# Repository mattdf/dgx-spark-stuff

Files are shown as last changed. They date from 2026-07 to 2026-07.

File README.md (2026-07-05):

# DGX Spark Stuff

This repo will collect various DGX Spark-related work over time. 

## OpenSCAD Rack for 4x Sparks

[CAD](CAD): OpenSCAD-based stackable DGX Spark rack, along with exported STL parts and a reference render. The CAD folder includes the main source model, printable tray/top/joiner exports (4-spark rack configuration), and a DGX Spark reference body used for fit and preview.

I suggest printing this in PC (or PETG if you really can't print PC), because the surface temperatures of the sparks can get up to 60c under high load long term, and PLA has a glass transition temperature of ~55c so it will soften too much under load. The bottom tray can be PLA, but using PC for the rest is best.

<table align="center">
	<tr>
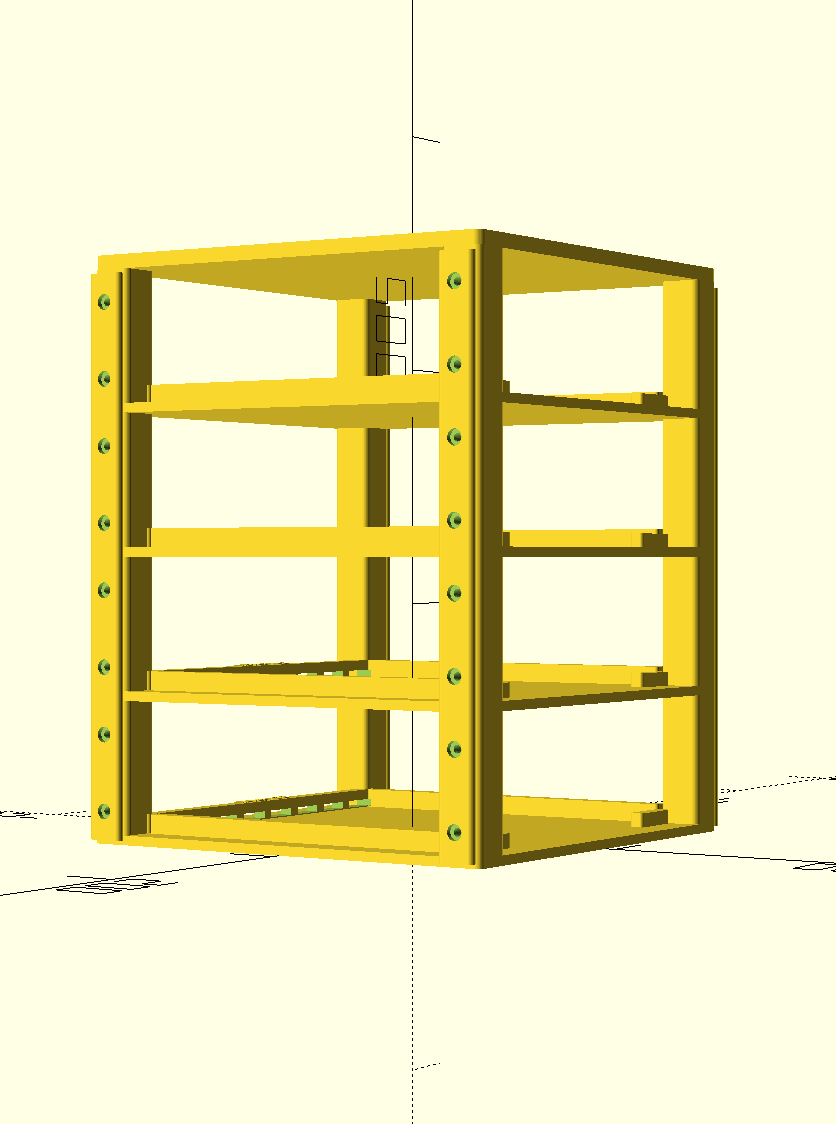
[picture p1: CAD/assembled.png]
Rendered assembly
		<td align="center"></td>
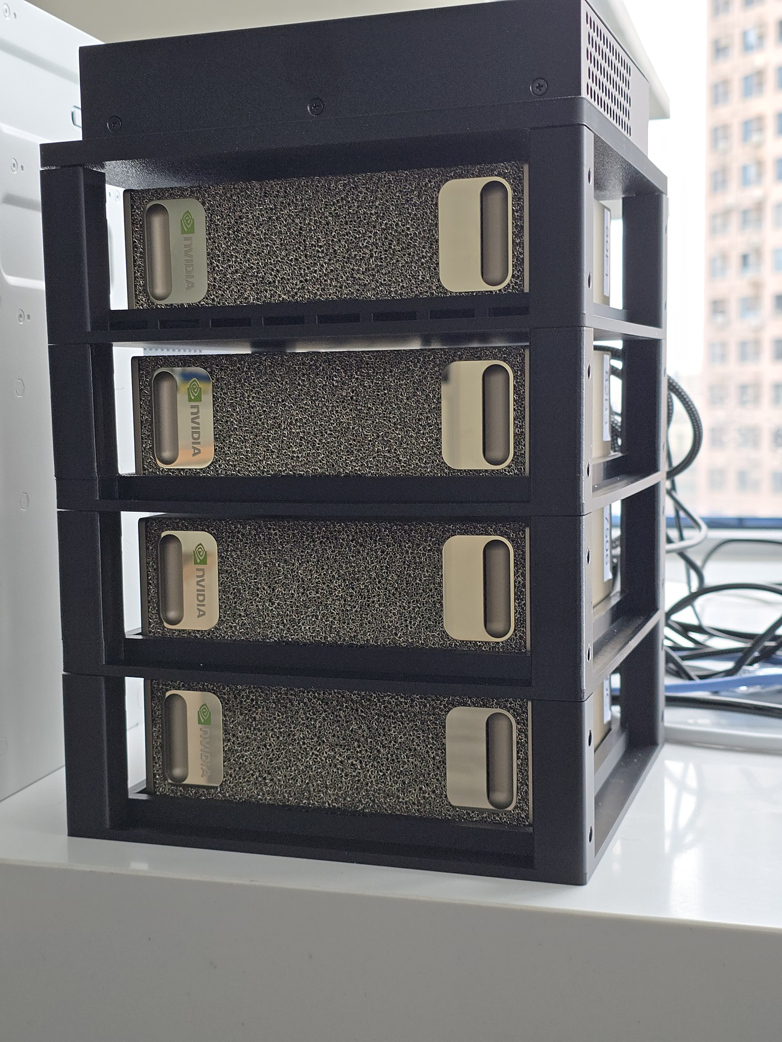
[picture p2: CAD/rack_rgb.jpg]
Real assembly
		<td align="center"></td>
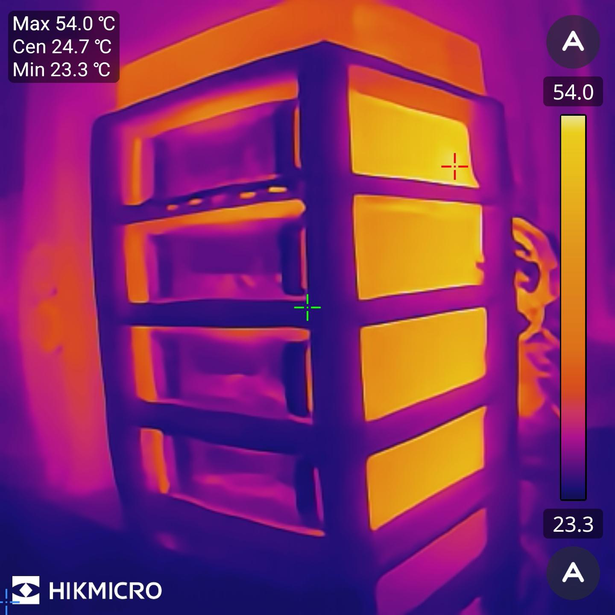
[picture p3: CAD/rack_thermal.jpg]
Thermal view
		<td align="center"></td>
	</tr>
	<tr>
		<td align="center">Rendered assembly</td>
		<td align="center">Real assembly</td>
		<td align="center">Thermal view</td>
	</tr>
</table>

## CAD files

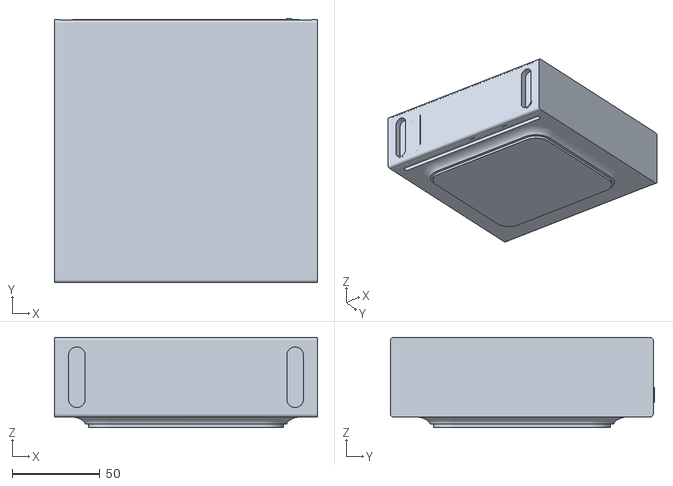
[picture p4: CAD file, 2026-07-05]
CAD/dgx_spark_ref.stl
150.0 x 150.8 x 51.5

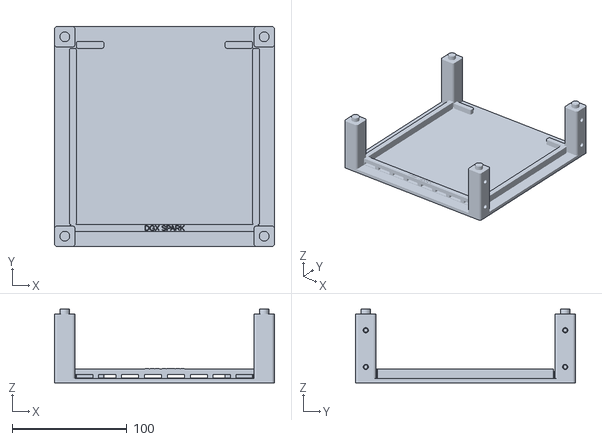
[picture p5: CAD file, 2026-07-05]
CAD/tray.stl
192.0 x 192.0 x 64.6

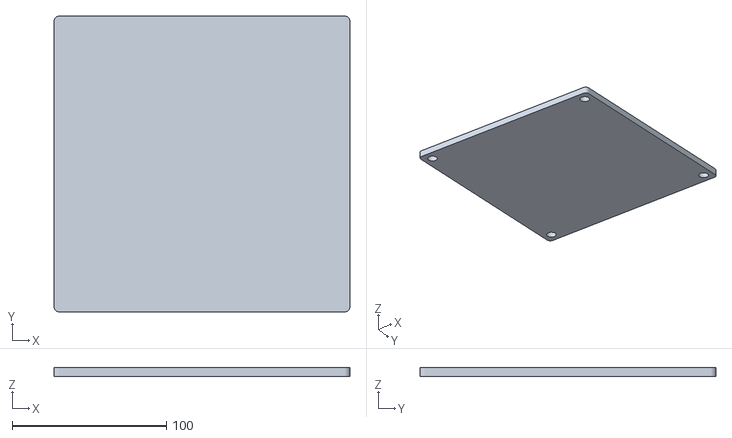
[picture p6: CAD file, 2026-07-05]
CAD/top_slice.stl
192.0 x 192.0 x 6.00

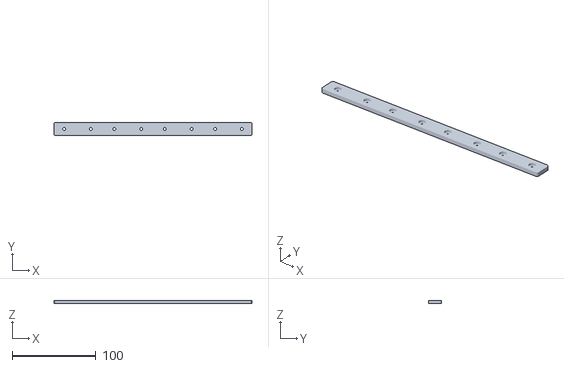
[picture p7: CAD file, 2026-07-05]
CAD/side_joiner.stl
236.0 x 16.0 x 4.00

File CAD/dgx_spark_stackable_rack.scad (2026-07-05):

/*
  Printable stackable 4x rack for NVIDIA DGX Spark

  DGX Spark reference body dimensions used:
    150 mm L x 150 mm W x 50.5 mm H

  This version is designed for FDM printing without support:
    - tray exports bottom-flat; no downward feet
    - no suspended top perimeter frame or long bridges
    - separate flat side joiners instead of tall upright straps
    - lateral brass-insert pockets use printable teardrop geometry
    - tray-to-tray alignment uses separate dowel pins and socket pockets

  Print/export modes:
    part = "stack4";        // preview full 4x assembly, including roof if enabled
    part = "tray";          // print 4x
    part = "top_slice";     // print 1x roof cap; same footprint as tray floor, no columns
    part = "side_joiner";   // print 12x for a fixed 4-stack; 4 per seam
    part = "align_pin";     // print 16x with roof, 12x without, or replace with 8 mm OD dowel pins
    part = "device";        // DGX Spark reference placeholder only

  Hardware:
    - M3 heat-set inserts, default pocket: 4.6 mm OD x 5.8 mm deep
    - M3 x 10 mm button/socket-head screws for side joiners
    - populate 32 inserts if every tray should remain independently stackable
      in either direction; only 24 are used in a fixed 4-stack.

  Coordinate convention:
    - X = width
    - Y = depth, rear I/O/cable side at +Y
    - Z = height
*/

module dgx_spark_ref() {
    // credit: SchwickSchwimmer @ https://www.printables.com/model/1512927-nvidia-dgx-spark
    import("./dgx_spark_ref.stl");
}

$fn = 48;

front_label = "DGX SPARK";

part = "stack4";
show_device_preview = false;
show_joiners = true;
show_alignment_pins = true;
show_top_slice = true;
show_front_label = true;

enable_base_vent = false;

// ---- DGX Spark reference dimensions ----
dgx_w = 150;
dgx_d = 150;
dgx_h = 50.5;
rack_u = 44.45;

// ---- Tray fit and stack geometry ----
fit_clearance_xy = 2.0;
top_clearance = 5.5;
floor_t = 4.0;
tray_h = 60.0;             // floor_t + dgx_h + top_clearance
stack_count = 4;

cavity_w = dgx_w + 2 * fit_clearance_xy;
cavity_d = dgx_d + 2 * fit_clearance_xy;

outer_w = 192;
outer_d = 192;

// The roof cap is deliberately only the tray-floor slice: no columns, no lips.
top_slice_t = floor_t;
top_slice_pad = floor_t/2;

post_size = 18;
post_cx = outer_w / 2 - post_size / 2;
post_cy = outer_d / 2 - post_size / 2;

rail_t = 6;
rail_h = 8;
rear_keeper_w = 24;
rear_keeper_h = 6; 

// ---- Alignment sockets and removable pins ----
align_pin_d = 8.8;
align_pin_h = 8.0;
align_pin_chamfer_h = 0.8;
socket_d = 8.8;
socket_clear_depth = align_pin_h / 2 + 0.5;
socket_roof_h = socket_d / 2;   // conic roof removes bottom-socket bridging

// ---- Heat-set inserts and screws ----
insert_od = 4.6;
insert_depth = 5.8;
insert_relief_d = 3.4;
insert_relief_depth = 4.0;
insert_teardrop_rise = 0.0;//1.1;
side_insert_z_bottom = 14;
side_insert_z_top = tray_h - 14;

m3_clearance_d = 3.4;
m3_head_d = 6.6;
m3_head_depth = 2.2;

// ---- Seam joiners ----
joiner_t = 4.0;
joiner_w = 16.0;
joiner_h = 118.0*2; // 44*x
joiner_gap = 0.35;
joiner_hole_offset = 14.0;  // aligns with top/bottom tray insert positions

eps = 0.05;

assert(tray_h >= floor_t + dgx_h + top_clearance,
       "tray_h is smaller than floor_t + dgx_h + top_clearance");
assert(outer_w >= cavity_w + 2 * post_size,
       "outer_w too small for DGX cavity plus posts");
assert(outer_d >= cavity_d + 2 * post_size,
       "outer_d too small for DGX cavity plus posts");

// ---------- helpers ----------

module rounded_square_2d(size, r = 2, center = true) {
  rr = max(0.01, min(r, min(size[0], size[1]) / 2 - 0.01));
  offset(r = rr)
    square([size[0] - 2 * rr, size[1] - 2 * rr], center = center);
}

module rbox(size, r = 2, center = true) {
  if (center) {
    translate([0, 0, -size[2] / 2])
      linear_extrude(height = size[2])
        rounded_square_2d([size[0], size[1]], r, true);
  } else {
    linear_extrude(height = size[2])
      rounded_square_2d([size[0], size[1]], r, false);
  }
}

module rboxc(size, pos = [0, 0, 0], r = 2) {
  translate(pos) rbox(size, r, true);
}

module rboxuc(size, pos = [0, 0, 0], r = 2) {
  translate(pos) rbox(size, r, false);
}


module teardrop_2d_xup(d, rise = 1.0) {
  r = d / 2;
  union() {
    circle(r = r);
    if (rise > 0.0)
    polygon(points = [[0, -r], [r + rise, 0], [0, r]]);
  }
}

module teardrop_hole_x(d, depth, rise = 1.0) {
  // Local +X of the 2D profile maps to global +Z, so the point is upward.
  rotate([0, -90, 0])
    linear_extrude(height = depth, center = true)
      teardrop_2d_xup(d, rise);
}

module corner_positions() {
  for (sx = [-1, 1])
    for (sy = [-1, 1])
      translate([sx * post_cx, sy * post_cy, 0]) children();
}

// ---------- tray cutouts/features ----------

module base_vent_slots() {
  slot_w = 4;
  slot_len = dgx_d - 16;
  for (x = [-52, -26, 0, 26, 52])
    rboxc([slot_w, slot_len, floor_t + 10 + 2 * eps], [x, 0, floor_t / 2], r = 4);
}

module top_alignment_socket_voids() {
  corner_positions()
    translate([0, 0, tray_h - socket_clear_depth])
      cylinder(d = socket_d, h = socket_clear_depth + eps);
}

module top_alignment_socket_pins() {
  corner_positions()
    translate([0, 0, tray_h ])
      cylinder(d = socket_d-0.2, h = socket_clear_depth + eps);
}

module bottom_alignment_socket_voids() {
  corner_positions()
    translate([0, 0, -eps]) {
      cylinder(d = socket_d, h = socket_clear_depth + eps);
      translate([0, 0, socket_clear_depth])
        cylinder(d1 = socket_d, d2 = 0.4, h = socket_roof_h);
    }
}

module side_insert_pocket_at(sx, sy, zpos) {
  // Main heat-set pocket, open from left/right outside face.
  translate([sx * (outer_w / 2 - insert_depth / 2 + eps),
             sy * post_cy,
             zpos])
    teardrop_hole_x(insert_od, insert_depth + 2 * eps, insert_teardrop_rise);

  // Smaller screw-tip relief just behind the insert.
  translate([sx * (outer_w / 2 - insert_depth - insert_relief_depth / 2 + eps),
             sy * post_cy,
             zpos])
    teardrop_hole_x(insert_relief_d, insert_relief_depth + 2 * eps, insert_teardrop_rise);
}

module side_insert_pockets() {
  for (sx = [-1, 1])
    for (sy = [-1, 1])
      for (zpos = [side_insert_z_bottom, side_insert_z_top])
        side_insert_pocket_at(sx, sy, zpos);
}

module front_label_marking() {
  if (show_front_label) {
    translate([0, -(cavity_d / 2 + rail_t / 2), floor_t + rail_h + 0.05])
      linear_extrude(height = 0.55)
        text(front_label, size = 4.5, halign = "center", valign = "center");
  }
}

// ---------- main printable tray ----------

module spark_tray() {
  difference() {
    union() {
      // Flat print bed contact: entire underside starts at Z=0.
      rboxc([outer_w, outer_d, floor_t], [0, 0, floor_t / 2], r = 3.5);

      // Four vertical load posts. No top frame; the next tray bears on these posts.
      corner_positions()
        rboxc([post_size, post_size, tray_h], [0, 0, tray_h / 2], r = 2.5);

      // Low DGX retention lips. Rear center remains open for I/O and cables.
      rboxc([rail_t, cavity_d, rail_h],
            [-(cavity_w / 2 + rail_t / 2), 0, floor_t + rail_h / 2], r = 1.4);
      rboxc([rail_t, cavity_d, rail_h],
            [ (cavity_w / 2 + rail_t / 2), 0, floor_t + rail_h / 2], r = 1.4);
      rboxc([cavity_w + 2 * rail_t, rail_t, rail_h],
            [0, -(cavity_d / 2 + rail_t / 2), floor_t + rail_h / 2], r = 1.4);

      for (sx = [-1, 1])
        rboxc([rear_keeper_w, rail_t, rear_keeper_h],
              [sx * (cavity_w / 2 - rear_keeper_w / 2),
               cavity_d / 2 + rail_t / 2,
               floor_t + rear_keeper_h / 2], r = 1.3);

      front_label_marking();
      
      top_alignment_socket_pins();
    }
    
    if (enable_base_vent)
        base_vent_slots();
    bottom_alignment_socket_voids();
    side_insert_pockets();
    for (sx = [0 : 20 : 140]) {
          rboxuc([15, rail_t+4, 3],
            [-(cavity_w/2) + sx - 0.5, -(cavity_d / 2 + rail_t +2), floor_t +0.5], r = 0);
    }
  }
}

// ---------- separate printable roof cap ----------

module top_slice_pin_holes() {
  // Through-holes avoid blind-hole bridging and still capture the top alignment pins.
  corner_positions()
    translate([0, 0, -eps])
      cylinder(d = socket_d, h = top_slice_t + 2 + 2 * eps);
}

module top_slice() {
  difference() {
    rboxc([outer_w, outer_d, top_slice_t + top_slice_pad],
          [0, 0, top_slice_t ], r = 3.5);
      
    if (enable_base_vent)
        base_vent_slots();
    top_slice_pin_holes();
  }
}

// ---------- separate printable alignment pin ----------
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

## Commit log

2026-07-05 CAD rack
    [dgx_spark_ref.stl, dgx_spark_stackable_rack.scad, side_joiner.stl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]
2026-07-05 update cad readme
